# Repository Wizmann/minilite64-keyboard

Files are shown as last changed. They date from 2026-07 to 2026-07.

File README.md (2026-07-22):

# Minilite64 Keyboard

Minilite64 is a 64-key hot-swap keyboard built around a Waveshare
RP2040-Zero.  Its main PCB uses two copper layers; the Vial firmware exposes
four dynamic keymap layers.  The main keyboard PCB and controller carrier are
connected by a 21 mm-wide, 100 mm-long, 20-position 1.0 mm Type-A FFC.  The
design has no per-key lighting.

Assembly is main-board first and controller last.  Lock the main FFC end before
fastening the main PCB, connect the carrier/cover outside the case, then guide
the smooth rear service loop home and install the carrier-cover screws.

## Release contents

- `hardware/keyboard/Minilite64.kicad_pcb` — routed GH60-size main PCB
- `hardware/controller/RP2040_Zero_Carrier.kicad_pcb` — routed 40 x 36 mm carrier
- `hardware/mechanical/Minilite64_plate_fixed.dxf` — corrected plate for PC/FR4 ordering
- `hardware/mechanical/*.stl` and `*.step` — full-size and A1 standing mechanical parts
- `manufacturing/*_gerber.zip` — order-ready PCB packages
- `firmware/vial-qmk/keyboards/minilite64` — Vial-QMK keyboard source
- `firmware/releases/Minilite64_vial.uf2` — locally verified RP2040 firmware
- `docs/DESIGN_AND_REUSE_GUIDE.md` — design history, assembly notes, checks, and reusable lessons

Both PCBs currently report zero DRC violations and zero unconnected items.
The mechanical review reports zero intersections for the checked component,
mounting, controller, stabilizer, cover, and cable envelopes.
The main PCB front silkscreen also carries the complete corrected plate DXF at
1:1 scale for visual Gerber and bare-board inspection.

The checked-in UF2 was built with `arm-none-eabi-gcc 13.2.1`; its SHA-256 is
recorded in `firmware/releases/SHA256SUMS.txt`.

The current mechanical package is **prototype-only** until a real 100 mm FFC
has been installed and repeatedly serviced in a printed case.  Automated solid
checks cannot prove that a flexible cable will settle into the modeled scroll.

## Important fabrication note

Use `hardware/mechanical/Minilite64_plate_fixed.dxf`, not the original
`plate.dxf`.  The original drawing contains an obsolete screw relief merged
into the bottom-row Menu switch opening.  The fixed file removes that conflict
and adds two balanced bottom-row supports, for five round mounts plus two side
mounting slots in total.

See the [design and reuse guide](docs/DESIGN_AND_REUSE_GUIDE.md) before ordering
or assembling the first prototype.

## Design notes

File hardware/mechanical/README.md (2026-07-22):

# Mechanical File Manifest

Files with the same base name describe the same geometry in different formats:

- `.FCStd` — editable FreeCAD document.
- `.step` — neutral CAD exchange file for inspection, modification, or machining.
- `.stl` — triangulated mesh for slicers and 3D printing.

## Assembly review

- `Minilite64_assembly_review.FCStd`
- `Minilite64_assembly_review.step`
- `Minilite64_assembly_review.stl`

Combined case, cover, main PCB, plate, carrier, component keep-outs,
stabilizers, and spacers.  Use it to inspect placement and interference.  It is
not a single printable part.

## Case

- `Minilite64_case_full.*` — one-piece case in assembled orientation.  It uses
  a 307 x 106.5 mm Linhai/Case.step-inspired GH60-style plan, R5 plan corners,
  a 5 degree wedge, a 20.0 mm spacebar side, and a 29.318 mm number-row side.
  The tapered wall,
  R2 hand-contact rim, C1.2 lower edge break, and internal ribs follow the
  supplied references.  There is no controller tongue or rear projection.
- `Minilite64_case_A1_standing.*` — the same one-piece case rotated onto its
  front wall and 45 degrees across the bed.  Its stored bounds are about
  236.3 x 236.3 x 106.3 mm, so it fits the Bambu A1 with room for an
  approximately 8 mm brim.  Use this file for the preferred one-piece print.

The RP2040 carrier, service cover, USB-C tunnel, and rear-wall FFC service-loop
pocket are custom internal features.  They do not change the selected
rectangular outside envelope.

The PCB/plate stack and its seven mounting axes follow the 5 degree typing
plane; the carrier remains horizontal at the bottom for service access.

The 100 mm FFC is a service tether.  Connect and fasten the main PCB first,
connect the carrier/cover outside the case, then guide the smooth scroll into
its rounded rear pocket and install the cover screws.  The controller can be
removed later without disturbing the main PCB.

`Minilite64_assembly_review.*` also contains a named 65 mm controller service
pose with tangent cable exits.  The modeled service path is 94.762 mm long,
keeps 5.238 mm slack, reaches R3.6 at the fixed rear hairpin, and keeps the
cubic drop above R4.82.  The 81.625 mm straight-line value is only a theoretical
upper bound.  Use an FFC flexible body no thicker than 0.20 mm; the reinforced
ends may be 0.30 mm.

This package is prototype-only until a real cable has been fitted.  A solid
model cannot prove that the flexible strip will settle into the ideal scroll
instead of buckling during cover insertion.

The bottom has four circular pockets for nominal Ø10 x 1.5-2.0 mm adhesive
silicone feet.  Each pocket has an Ø11.2 mm body, 0.65 mm depth, and an Ø12 mm
tapered opening.  The extra diameter tolerates placement error; the shallow
lead-in avoids a sharp unsupported lip when the case is printed standing.

## Controller service part

- `Minilite64_service_cover.*` — removable bottom cover carrying the 40 x
  36 mm RP2040-Zero carrier.  It includes four carrier posts, cover screw
  holes, and a closed outside surface.  Remove the cover if physical
  BOOT/RESET recovery is ever required.

## Plate

- `Minilite64_plate_fixed.dxf` — corrected 1.5 mm plate drawing for PC/FR4
  fabrication.  This is the DXF to send to the plate vendor.
- `Minilite64_plate_print_fixed.*` — one-piece, 1.5 mm printable plate for a
  large printer.  It is primarily a fit-check model.
- `Minilite64_plate_A1_fitcheck.stl` — one A1-ready STL containing two flat
  printable halves.  The loose stepped joint avoids complete switch openings,
  uses a 0.4 mm total seam gap, and relies on switches and PCB screws for final
  alignment.  No glue is required for fit checking.
- `Minilite64_plate_spacer_print_7x.*` — 5 mm plate-to-PCB spacer; print seven
  copies, one at each retained mounting location.

The original root-level `plate.dxf` is preserved for provenance.  Do not send
it to manufacturing: it contains an obsolete screw relief merged into the
bottom-row Menu switch opening.  The files in this directory remove that
collision and add two symmetric bottom-row supports.  The finished plate has
five round mounts and two side mounting slots.

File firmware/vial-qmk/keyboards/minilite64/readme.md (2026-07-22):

# Minilite64 Vial firmware

Copy this directory to `vial-qmk/keyboards/minilite64`, then build with:

```sh
make minilite64:vial
```

Hold the top-left key while plugging in for Bootmagic reset. The default Fn1
layer also places `QK_BOOT` on the top-left key. Normal Vial remapping never
requires the physical BOOT/RESET buttons.

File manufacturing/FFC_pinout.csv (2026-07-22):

Main J1 pin | Carrier J1 pin | Net | RP2040-Zero pad
1 | 1 | COL0 | GP13
2 | 2 | COL1 | GP12
3 | 3 | COL2 | GP11
4 | 4 | COL3 | GP10
5 | 5 | COL4 | GP9
6 | 6 | COL5 | GP8
7 | 7 | COL6 | GP7
8 | 8 | COL7 | GP6
9 | 9 | COL8 | GP5
10 | 10 | COL9 | GP4
11 | 11 | COL10 | GP3
12 | 12 | COL11 | GP2
13 | 13 | COL12 | GP1
14 | 14 | COL13 | GP0
15 | 15 | ROW0 | GP29
16 | 16 | ROW1 | GP28
17 | 17 | ROW2 | GP27
18 | 18 | ROW3 | GP26
19 | 19 | ROW4 | GP15
20 | 20 | GND | GND

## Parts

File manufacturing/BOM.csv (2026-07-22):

Reference(s) | Qty | Value | Package | Assembly | Notes
SW1-SW64 | 64 | Kailh MX hot-swap socket CPG151101S11 | Kailh hotswap SMD | Hand solder | Socket on PCB bottom
D1-D64 | 64 | 1N4148W | SOD-123 | Hand solder | Large hand-solder pads; cathode stripe to ROW
J1 (main), J1 (carrier) | 2 | 20P 1.0mm bottom-contact flip-lock FFC/FPC connector | 20P 1.0mm SMT | Hand solder | Generic or equivalent; verify same footprint
FFC1 | 1 | 20P 1.0mm Type-A FFC, 100mm x 21mm | Same-side contacts | Purchased cable | No axial twist; flexible body <=0.20mm; prototype-fit the smooth service scroll
U1 | 1 | Waveshare RP2040-Zero 23.5x18mm USB-C | Castellated module | Hand solder | Mount component-side up; USB toward rear
H1-H5 main | 5 | M2 screw + 3.2x3mm heat-set insert | Mechanical | Assembly | Three original mounts plus two balanced bottom-row supports
S1-S2 main sides | 2 | M2 screw + 3.2x3mm heat-set insert | Mechanical | Assembly | Left/right DXF edge slots; screw heads retain PCB and plate
H1-H4 carrier | 4 | M2 screw + heat-set insert | Mechanical | Assembly | Four-corner mounting

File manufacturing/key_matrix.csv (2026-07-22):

Reference | Label | Matrix row | Matrix column | X mm | Y mm | Width U
SW1 | ~/` | 0 | 0 | 9.525 | 9.525 | 1.0
SW2 | !/1 | 0 | 1 | 28.575 | 9.525 | 1.0
SW3 | @/2 | 0 | 2 | 47.625 | 9.525 | 1.0
SW4 | #/3 | 0 | 3 | 66.675 | 9.525 | 1.0
SW5 | $/4 | 0 | 4 | 85.725 | 9.525 | 1.0
SW6 | %/5 | 0 | 5 | 104.775 | 9.525 | 1.0
SW7 | ^/6 | 0 | 6 | 123.825 | 9.525 | 1.0
SW8 | &/7 | 0 | 7 | 142.875 | 9.525 | 1.0
SW9 | */8 | 0 | 8 | 161.925 | 9.525 | 1.0
SW10 | (/9 | 0 | 9 | 180.975 | 9.525 | 1.0
SW11 | )/0 | 0 | 10 | 200.025 | 9.525 | 1.0
SW12 | _/- | 0 | 11 | 219.075 | 9.525 | 1.0
SW13 | +/= | 0 | 12 | 238.125 | 9.525 | 1.0
SW14 | Backspace | 0 | 13 | 266.700 | 9.525 | 2.0
SW15 | Tab | 1 | 0 | 14.288 | 28.575 | 1.5
SW16 | Q | 1 | 1 | 38.100 | 28.575 | 1.0
SW17 | W | 1 | 2 | 57.150 | 28.575 | 1.0
SW18 | E | 1 | 3 | 76.200 | 28.575 | 1.0
SW19 | R | 1 | 4 | 95.250 | 28.575 | 1.0
SW20 | T | 1 | 5 | 114.300 | 28.575 | 1.0
SW21 | Y | 1 | 6 | 133.350 | 28.575 | 1.0
SW22 | U | 1 | 7 | 152.400 | 28.575 | 1.0
SW23 | I | 1 | 8 | 171.450 | 28.575 | 1.0
SW24 | O | 1 | 9 | 190.500 | 28.575 | 1.0
SW25 | P | 1 | 10 | 209.550 | 28.575 | 1.0
SW26 | {/[ | 1 | 11 | 228.600 | 28.575 | 1.0
SW27 | }/] | 1 | 12 | 247.650 | 28.575 | 1.0
SW28 | |/\ | 1 | 13 | 271.463 | 28.575 | 1.5
SW29 | Caps Lock | 2 | 0 | 16.669 | 47.625 | 1.75
SW30 | A | 2 | 1 | 42.863 | 47.625 | 1.0
SW31 | S | 2 | 2 | 61.913 | 47.625 | 1.0
SW32 | D | 2 | 3 | 80.963 | 47.625 | 1.0
SW33 | F | 2 | 4 | 100.013 | 47.625 | 1.0
SW34 | G | 2 | 5 | 119.062 | 47.625 | 1.0
SW35 | H | 2 | 6 | 138.113 | 47.625 | 1.0
SW36 | J | 2 | 7 | 157.162 | 47.625 | 1.0
SW37 | K | 2 | 8 | 176.213 | 47.625 | 1.0
SW38 | L | 2 | 9 | 195.263 | 47.625 | 1.0
SW39 | :/; | 2 | 10 | 214.312 | 47.625 | 1.0
SW40 | "/' | 2 | 11 | 233.363 | 47.625 | 1.0
SW41 | Enter | 2 | 12 | 264.319 | 47.625 | 2.25
SW42 | Shift | 3 | 0 | 21.431 | 66.675 | 2.25
SW43 | Z | 3 | 1 | 52.388 | 66.675 | 1.0
SW44 | X | 3 | 2 | 71.438 | 66.675 | 1.0
SW45 | C | 3 | 3 | 90.487 | 66.675 | 1.0
SW46 | V | 3 | 4 | 109.538 | 66.675 | 1.0
SW47 | B | 3 | 5 | 128.588 | 66.675 | 1.0
SW48 | N | 3 | 6 | 147.638 | 66.675 | 1.0
SW49 | M | 3 | 7 | 166.688 | 66.675 | 1.0
SW50 | </, | 3 | 8 | 185.738 | 66.675 | 1.0
SW51 | >/. | 3 | 9 | 204.787 | 66.675 | 1.0
SW52 | ?// | 3 | 10 | 223.838 | 66.675 | 1.0
SW53 | Shift | 3 | 11 | 259.556 | 66.675 | 2.75
SW54 | Ctrl | 4 | 0 | 11.906 | 85.725 | 1.25
SW55 | Win | 4 | 1 | 35.719 | 85.725 | 1.25
SW56 | Alt | 4 | 2 | 59.531 | 85.725 | 1.25
SW57 | Fn1 | 4 | 3 | 83.344 | 85.725 | 1.25
SW58 |  | 4 | 4 | 121.444 | 85.725 | 2.75
SW59 | Fn2 | 4 | 5 | 159.544 | 85.725 | 1.25
SW60 | Menu | 4 | 6 | 183.356 | 85.725 | 1.25
SW61 | Fn3 | 4 | 7 | 204.787 | 85.725 | 1.0
SW62 | Alt | 4 | 8 | 226.219 | 85.725 | 1.25
SW63 | Win | 4 | 9 | 250.031 | 85.725 | 1.25
SW64 | Ctrl | 4 | 10 | 273.844 | 85.725 | 1.25

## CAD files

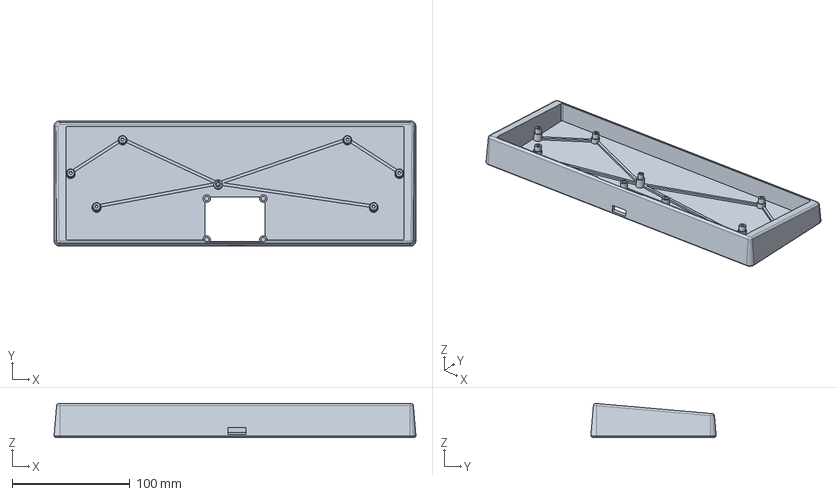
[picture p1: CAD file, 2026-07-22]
hardware/mechanical/Minilite64_case_full.step
306.8 x 106.3 x 28.9 mm

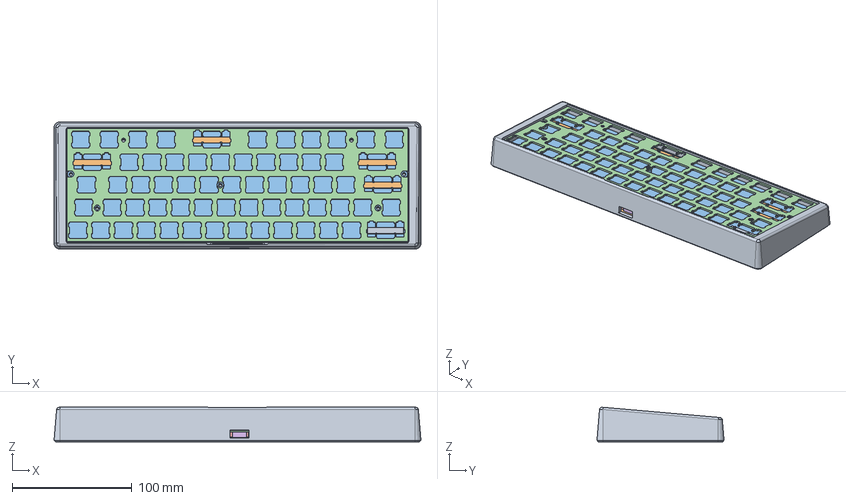
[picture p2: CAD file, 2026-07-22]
hardware/mechanical/Minilite64_assembly_review.step
306.8 x 106.3 x 28.9 mm

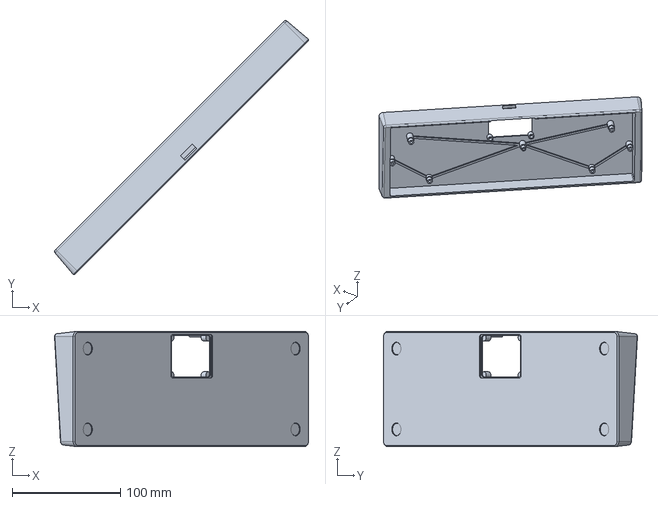
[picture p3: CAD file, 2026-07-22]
hardware/mechanical/Minilite64_case_A1_standing.step
234.2 x 234.2 x 106.3 mm

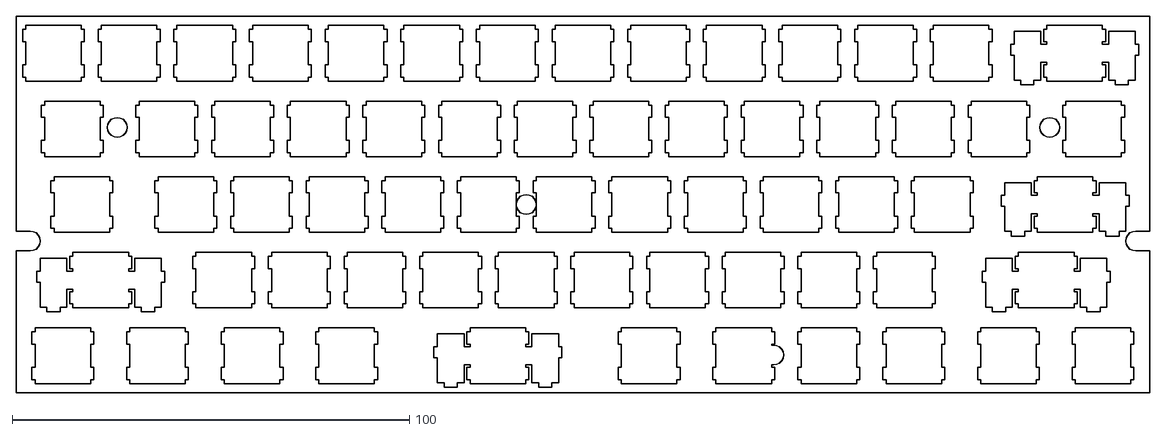
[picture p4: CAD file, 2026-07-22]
plate.dxf
285.4 x 94.9

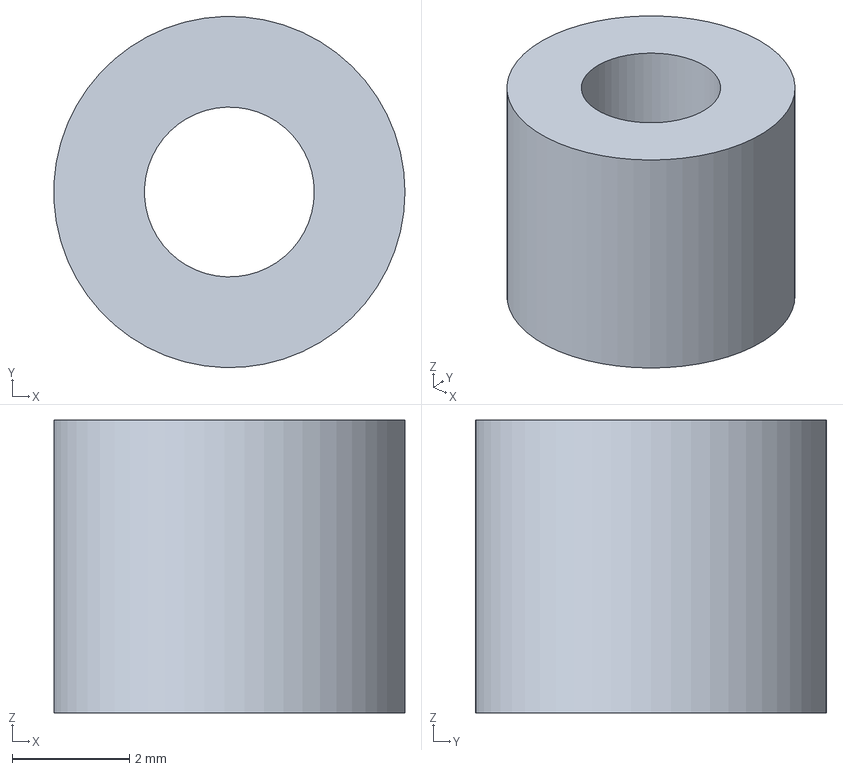
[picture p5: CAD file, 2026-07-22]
hardware/mechanical/Minilite64_plate_spacer_print_7x.step
6.00 x 6.00 x 5.00 mm

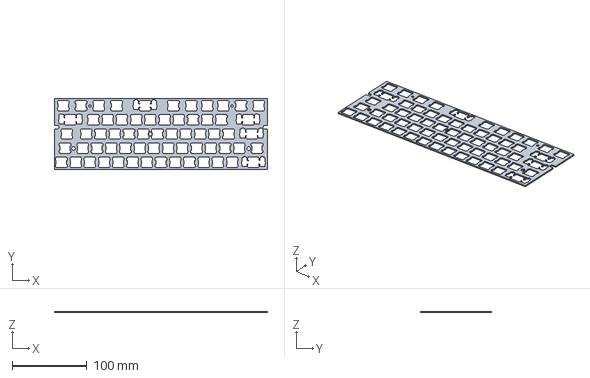
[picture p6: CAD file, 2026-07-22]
hardware/mechanical/Minilite64_plate_print_fixed.step
285.4 x 94.9 x 1.50 mm

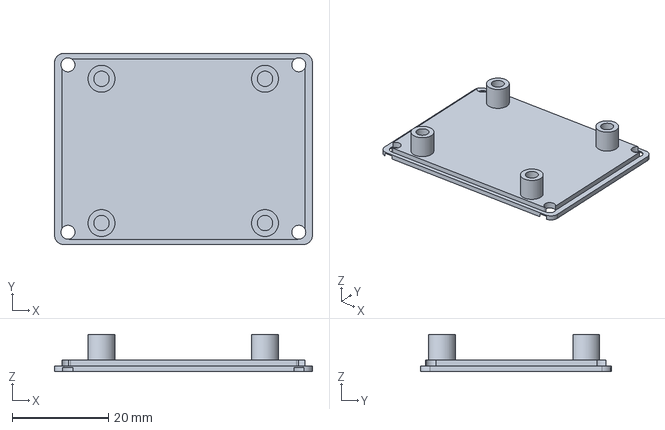
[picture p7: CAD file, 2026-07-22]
hardware/mechanical/Minilite64_service_cover.step
53.7 x 39.8 x 7.70 mm

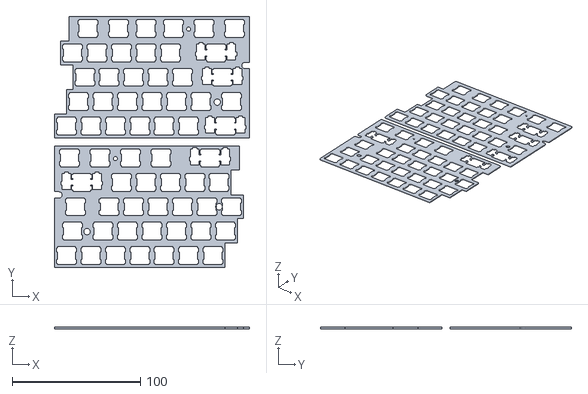
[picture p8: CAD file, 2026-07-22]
hardware/mechanical/Minilite64_plate_A1_fitcheck.stl
152.0 x 195.9 x 1.50

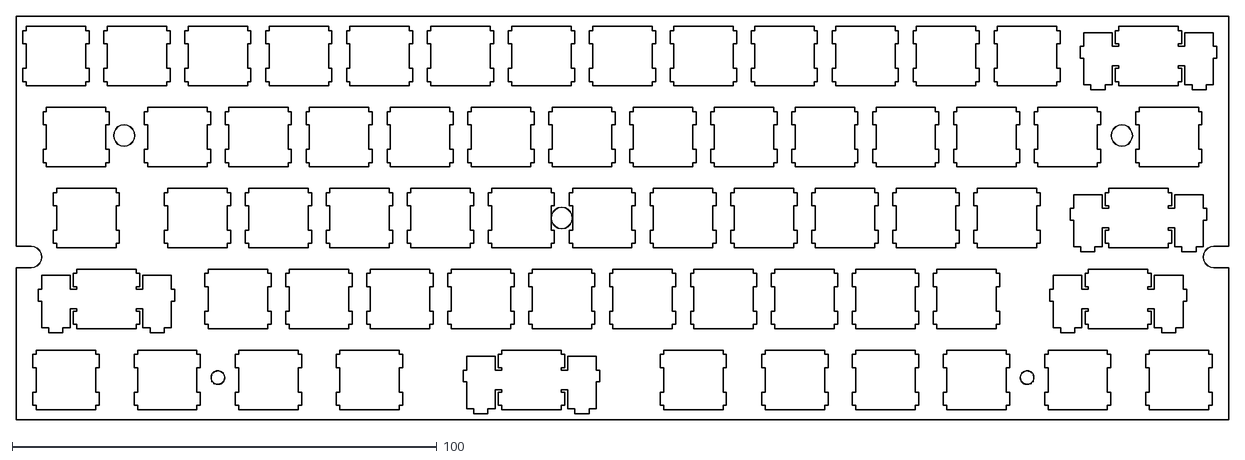
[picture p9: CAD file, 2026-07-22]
hardware/mechanical/Minilite64_plate_fixed.dxf
285.4 x 94.9

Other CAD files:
hardware/mechanical/Minilite64_plate_spacer_print_5x.step
hardware/mechanical/Minilite64_assembly_review.FCStd
hardware/mechanical/Minilite64_assembly_review.stl
hardware/mechanical/Minilite64_case_A1_standing.FCStd
hardware/mechanical/Minilite64_case_A1_standing.stl
hardware/mechanical/Minilite64_case_full.FCStd
hardware/mechanical/Minilite64_case_full.stl
hardware/mechanical/Minilite64_plate_print_fixed.FCStd
hardware/mechanical/Minilite64_plate_print_fixed.stl
hardware/mechanical/Minilite64_plate_spacer_print_7x.FCStd
hardware/mechanical/Minilite64_plate_spacer_print_7x.stl
hardware/mechanical/Minilite64_service_cover.FCStd
hardware/mechanical/Minilite64_service_cover.stl

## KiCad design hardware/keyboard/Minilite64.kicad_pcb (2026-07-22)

Board: 2 copper layers, 134 parts (1 on the bottom side), 83 nets.

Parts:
D1, D2, D3, D4, D5, D6, D7, D8, D9, D10, D11, D12, D13, D14: 1N4148W SOD-123; SOD-123_HandSolder_Horizontal
D15, D16, D17, D18, D19, D20, D21, D22, D23, D24, D25, D26, D27, D28, D29, D30, D31, D32, D33, D34, D35, D36, D37, D38, D39, D40, D41, D42, D43, D44, D45, D46, D47, D48, D49, D50, D51, D52, D53, D54, D55, D56, D57, D58, D59, D60, D61, D62, D63, D64: 1N4148W SOD-123; SOD-123_HandSolder
H1, H2, H3: M2 clearance; MountingHole_2.7mm
H4, H5: M2 clearance; MountingHole_2.4mm
J1: 20P 1.0mm FFC ZIF bottom-contact; FFC_20P_1.0mm_BottomContact_Back
SW1: Kailh MX hotswap / ~ / `; Kailh_MX_Hotswap
SW2: Kailh MX hotswap / ! / 1; Kailh_MX_Hotswap
SW3: Kailh MX hotswap / @ / 2; Kailh_MX_Hotswap
SW4: Kailh MX hotswap / # / 3; Kailh_MX_Hotswap
SW5: Kailh MX hotswap / $ / 4; Kailh_MX_Hotswap
SW6: Kailh MX hotswap / % / 5; Kailh_MX_Hotswap
SW7: Kailh MX hotswap / ^ / 6; Kailh_MX_Hotswap
SW8: Kailh MX hotswap / & / 7; Kailh_MX_Hotswap
SW9: Kailh MX hotswap / * / 8; Kailh_MX_Hotswap
SW10: Kailh MX hotswap / ( / 9; Kailh_MX_Hotswap
SW11: Kailh MX hotswap / ) / 0; Kailh_MX_Hotswap
SW12: Kailh MX hotswap / _ / -; Kailh_MX_Hotswap
SW13: Kailh MX hotswap / + / =; Kailh_MX_Hotswap
SW14: Kailh MX hotswap / Backspace; Kailh_MX_Hotswap
SW15: Kailh MX hotswap / Tab; Kailh_MX_Hotswap
SW16: Kailh MX hotswap / Q; Kailh_MX_Hotswap
SW17: Kailh MX hotswap / W; Kailh_MX_Hotswap
SW18: Kailh MX hotswap / E; Kailh_MX_Hotswap
SW19: Kailh MX hotswap / R; Kailh_MX_Hotswap
SW20: Kailh MX hotswap / T; Kailh_MX_Hotswap
SW21: Kailh MX hotswap / Y; Kailh_MX_Hotswap
SW22: Kailh MX hotswap / U; Kailh_MX_Hotswap
SW23: Kailh MX hotswap / I; Kailh_MX_Hotswap
SW24: Kailh MX hotswap / O; Kailh_MX_Hotswap
SW25: Kailh MX hotswap / P; Kailh_MX_Hotswap
SW26: Kailh MX hotswap / { / [; Kailh_MX_Hotswap
SW27: Kailh MX hotswap / } / ]; Kailh_MX_Hotswap
SW28: Kailh MX hotswap / | / \; Kailh_MX_Hotswap
SW29: Kailh MX hotswap / Caps Lock; Kailh_MX_Hotswap
SW30: Kailh MX hotswap / A; Kailh_MX_Hotswap
SW31: Kailh MX hotswap / S; Kailh_MX_Hotswap
SW32: Kailh MX hotswap / D; Kailh_MX_Hotswap
SW33: Kailh MX hotswap / F; Kailh_MX_Hotswap
SW34: Kailh MX hotswap / G; Kailh_MX_Hotswap
SW35: Kailh MX hotswap / H; Kailh_MX_Hotswap
SW36: Kailh MX hotswap / J; Kailh_MX_Hotswap
SW37: Kailh MX hotswap / K; Kailh_MX_Hotswap
SW38: Kailh MX hotswap / L; Kailh_MX_Hotswap
SW39: Kailh MX hotswap / : / ;; Kailh_MX_Hotswap
SW40: Kailh MX hotswap / " / '; Kailh_MX_Hotswap
SW41: Kailh MX hotswap / Enter; Kailh_MX_Hotswap
SW42, SW53: Kailh MX hotswap / Shift; Kailh_MX_Hotswap
SW43: Kailh MX hotswap / Z; Kailh_MX_Hotswap
SW44: Kailh MX hotswap / X; Kailh_MX_Hotswap
SW45: Kailh MX hotswap / C; Kailh_MX_Hotswap
SW46: Kailh MX hotswap / V; Kailh_MX_Hotswap
SW47: Kailh MX hotswap / B; Kailh_MX_Hotswap
SW48: Kailh MX hotswap / N; Kailh_MX_Hotswap
SW49: Kailh MX hotswap / M; Kailh_MX_Hotswap
SW50: Kailh MX hotswap / < / ,; Kailh_MX_Hotswap
SW51: Kailh MX hotswap / > / .; Kailh_MX_Hotswap
SW52: Kailh MX hotswap / ? / /; Kailh_MX_Hotswap
SW54, SW64: Kailh MX hotswap / Ctrl; Kailh_MX_Hotswap
SW55, SW63: Kailh MX hotswap / Win; Kailh_MX_Hotswap
SW56, SW62: Kailh MX hotswap / Alt; Kailh_MX_Hotswap
SW57: Kailh MX hotswap / Fn1; Kailh_MX_Hotswap
SW58: Kailh MX hotswap /; Kailh_MX_Hotswap
SW59: Kailh MX hotswap / Fn2; Kailh_MX_Hotswap
SW60: Kailh MX hotswap / Menu; Kailh_MX_Hotswap
SW61: Kailh MX hotswap / Fn3; Kailh_MX_Hotswap

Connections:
COL0: J1.1, SW1.1, SW15.1, SW29.1, SW42.1, SW54.1
COL1: J1.2, SW2.1, SW16.1, SW30.1, SW43.1, SW55.1
COL2: J1.3, SW3.1, SW17.1, SW31.1, SW44.1, SW56.1
COL3: J1.4, SW4.1, SW18.1, SW32.1, SW45.1, SW57.1
COL4: J1.5, SW5.1, SW19.1, SW33.1, SW46.1, SW58.1
COL5: J1.6, SW6.1, SW20.1, SW34.1, SW47.1, SW59.1
COL6: J1.7, SW7.1, SW21.1, SW35.1, SW48.1, SW60.1
COL7: J1.8, SW8.1, SW22.1, SW36.1, SW49.1, SW61.1
COL8: J1.9, SW9.1, SW23.1, SW37.1, SW50.1, SW62.1
COL9: J1.10, SW10.1, SW24.1, SW38.1, SW51.1, SW63.1
COL10: J1.11, SW11.1, SW25.1, SW39.1, SW52.1, SW64.1
COL11: J1.12, SW12.1, SW26.1, SW40.1, SW53.1
COL12: J1.13, SW13.1, SW27.1, SW41.1
COL13: J1.14, SW14.1, SW28.1
KEY1_D: D1.1, SW1.2
KEY2_D: D2.1, SW2.2
KEY3_D: D3.1, SW3.2
KEY4_D: D4.1, SW4.2
KEY5_D: D5.1, SW5.2
KEY6_D: D6.1, SW6.2
KEY7_D: D7.1, SW7.2
KEY8_D: D8.1, SW8.2
KEY9_D: D9.1, SW9.2
KEY10_D: D10.1, SW10.2
KEY11_D: D11.1, SW11.2
KEY12_D: D12.1, SW12.2
KEY13_D: D13.1, SW13.2
KEY14_D: D14.1, SW14.2
KEY15_D: D15.1, SW15.2
KEY16_D: D16.1, SW16.2
KEY17_D: D17.1, SW17.2
KEY18_D: D18.1, SW18.2
KEY19_D: D19.1, SW19.2
KEY20_D: D20.1, SW20.2
KEY21_D: D21.1, SW21.2
KEY22_D: D22.1, SW22.2
KEY23_D: D23.1, SW23.2
KEY24_D: D24.1, SW24.2
KEY25_D: D25.1, SW25.2
KEY26_D: D26.1, SW26.2
KEY27_D: D27.1, SW27.2
KEY28_D: D28.1, SW28.2
KEY29_D: D29.1, SW29.2
KEY30_D: D30.1, SW30.2
KEY31_D: D31.1, SW31.2
KEY32_D: D32.1, SW32.2
KEY33_D: D33.1, SW33.2
KEY34_D: D34.1, SW34.2
KEY35_D: D35.1, SW35.2
KEY36_D: D36.1, SW36.2
KEY37_D: D37.1, SW37.2
KEY38_D: D38.1, SW38.2
KEY39_D: D39.1, SW39.2
KEY40_D: D40.1, SW40.2
KEY41_D: D41.1, SW41.2
KEY42_D: D42.1, SW42.2
KEY43_D: D43.1, SW43.2
KEY44_D: D44.1, SW44.2
KEY45_D: D45.1, SW45.2
KEY46_D: D46.1, SW46.2
KEY47_D: D47.1, SW47.2
KEY48_D: D48.1, SW48.2
KEY49_D: D49.1, SW49.2
KEY50_D: D50.1, SW50.2
KEY51_D: D51.1, SW51.2
KEY52_D: D52.1, SW52.2
KEY53_D: D53.1, SW53.2
KEY54_D: D54.1, SW54.2
KEY55_D: D55.1, SW55.2
KEY56_D: D56.1, SW56.2
KEY57_D: D57.1, SW57.2
KEY58_D: D58.1, SW58.2
KEY59_D: D59.1, SW59.2
KEY60_D: D60.1, SW60.2
KEY61_D: D61.1, SW61.2
KEY62_D: D62.1, SW62.2
KEY63_D: D63.1, SW63.2
KEY64_D: D64.1, SW64.2
ROW0: D1.2, D2.2, D3.2, D4.2, D5.2, D6.2, D7.2, D8.2, D9.2, D10.2, D11.2, D12.2, D13.2, D14.2, J1.15
ROW1: D15.2, D16.2, D17.2, D18.2, D19.2, D20.2, D21.2, D22.2, D23.2, D24.2, D25.2, D26.2, D27.2, D28.2, J1.16
ROW2: D29.2, D30.2, D31.2, D32.2, D33.2, D34.2, D35.2, D36.2, D37.2, D38.2, D39.2, D40.2, D41.2, J1.17
ROW3: D42.2, D43.2, D44.2, D45.2, D46.2, D47.2, D48.2, D49.2, D50.2, D51.2, D52.2, D53.2, J1.18
ROW4: D54.2, D55.2, D56.2, D57.2, D58.2, D59.2, D60.2, D61.2, D62.2, D63.2, D64.2, J1.19

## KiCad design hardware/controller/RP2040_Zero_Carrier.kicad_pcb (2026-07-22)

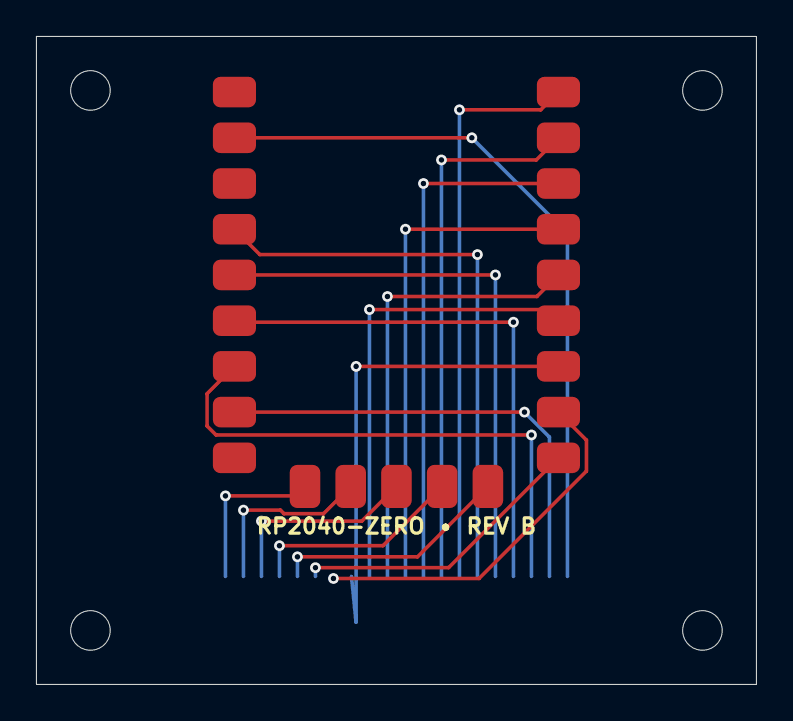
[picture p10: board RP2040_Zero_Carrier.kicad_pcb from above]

Board: 2 copper layers, 40.0 x 36.0 mm, 6 parts (1 on the bottom side), 20 nets.

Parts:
H1, H2, H3, H4: M2.5 clearance; MountingHole_2.2mm
J1: 20P 1.0mm FFC ZIF bottom-contact; FFC_20P_1.0mm_BottomContact_Back
U1: Waveshare RP2040-Zero; Waveshare_RP2040_Zero_Castellated

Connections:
COL0: J1.1, U1.GP13
COL1: J1.2, U1.GP12
COL2: J1.3, U1.GP11
COL3: J1.4, U1.GP10
COL4: J1.5, U1.GP9
COL5: J1.6, U1.GP8
COL6: J1.7, U1.GP7
COL7: J1.8, U1.GP6
COL8: J1.9, U1.GP5
COL9: J1.10, U1.GP4
COL10: J1.11, U1.GP3
COL11: J1.12, U1.GP2
COL12: J1.13, U1.GP1
COL13: J1.14, U1.GP0
GND: J1.20, U1.GND
ROW0: J1.15, U1.GP29
ROW1: J1.16, U1.GP28
ROW2: J1.17, U1.GP27
ROW3: J1.18, U1.GP26
ROW4: J1.19, U1.GP15

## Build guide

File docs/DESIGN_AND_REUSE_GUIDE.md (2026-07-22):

# Minilite64 Design, Assembly, and Reuse Guide

This document records how Minilite64 was designed, what was verified, what
failed during the process, and which practices should be reused on the next
keyboard project.  It is intentionally more explicit than a normal build
guide because the difficult parts were mechanical coordination and source-of-
truth management rather than the keyboard matrix itself.

## 1. Product definition

Minilite64 is based on the supplied 64-key KLE and plate DXF.  The confirmed
requirements are:

- 64 MX-compatible switches in a 5 x 14 sparse matrix.
- Kailh CPG151101S11-style hot-swap sockets on the PCB bottom.
- One hand-solderable SOD-123 1N4148W diode per key.
- No keyboard lighting.  The RP2040-Zero's onboard indicators are unaffected.
- A two-copper-layer main PCB with a rectangular GH60-style envelope and no PCB tongue.
- A separate Waveshare RP2040-Zero carrier.
- A 21 mm-wide, 100 mm-long, 20-position 1.0 mm Type-A/same-side FFC.
- Vial/VIA remapping, four dynamic layers, Bootmagic, and a firmware boot key.
- A PC or FR4 plate, 1.5 mm thick, plus printable verification plates.
- A Case.step-inspired wedge case, a bottom service cover, and a one-piece
  Bambu A1 standing print.

## 2. Electrical architecture

### Main PCB

The main PCB is 285.45 x 94.95 mm in its final edge-cut bounding box.  It uses
two copper layers, 0.20 mm minimum routed track width, 0.20 mm minimum routed
clearance, 0.30 mm vias, and a nominal 1.60 mm board thickness.

The switch matrix has five rows and fourteen columns.  Diode direction is
`COL2ROW`.  Both bottom-contact ZIF mouths face the number-row/rear side.  The
specified Type-A cable forms a smooth service scroll in the internal rear-wall pocket, so
the conductors stay flat without axial twist.  Pin numbers connect straight
through:

| Main J1 | Carrier J1 | Net | RP2040-Zero pad |
|---:|---:|---|---|
| 1 | 1 | COL0 | GP13 |
| 2-14 | 2-14 | COL1-COL13 | GP12 through GP0 |
| 15-19 | 15-19 | ROW0-ROW4 | GP29, GP28, GP27, GP26, GP15 |
| 20 | 20 | GND | GND |

The final main board includes seven usable mounting locations:

- Original round mounts: `(25.57496, 28.22478)`, `(128.57596, 47.62558)`, and
  `(260.42446, 28.22478)` mm.
- Balanced bottom-row M2 mounts: `(47.625, 85.20)` and `(238.125, 85.20)` mm.
- Side-slot screw axes: `(3.65, 56.824)` and `(282.10, 56.824)` mm.

The bottom-row screw relief near the Menu key is deliberately absent.  It
overlapped the switch opening and would have collided with the switch/hot-swap
assembly.  The two replacement mounts are symmetric about the keyboard center,
sit in full material between adjacent 1.25U switches, and avoid the spacebar
stabilizer.  The PCB uses 2.4 mm NPTH holes at these new locations; the plate
uses 3.2 mm clearance holes.

### RP2040-Zero carrier

The carrier is 40 x 36 mm with four 2.2 mm holes at `(3,3)`, `(37,3)`,
`(3,33)`, and `(37,33)` mm.  The RP2040-Zero is mounted on F.Cu and the FFC
connector is on B.Cu.  In the case, the module side faces the bottom service
cover.  The cover intentionally has no external BOOT/RESET opening.  Normal
remapping uses Vial and the keymap provides `QK_BOOT`; if damaged firmware
cannot enter its bootloader, remove the service cover to press the physical
buttons.  Removing the cover also brings the carrier out far enough to reach
the FFC latch without sharply folding the cable.

Do not regenerate the routed carrier from the old seed.  The generator now
writes an optional unrouted carrier seed only to `build/` when invoked with
`--write-carrier-seed`; it never overwrites the routed board in `hardware/`.

## 3. Coordinate systems and the plate correction

The most important geometry lesson was that the DXF Y axis and the KLE/KiCad Y
axis point in opposite directions.  Treating them as identical incorrectly
made a valid mounting hole appear to collide with Shift.

The conversion used here mirrors the DXF about its own center and maps that
center to the PCB center:

```text
pcb_x = dxf_x + pcb_center_x - dxf_center_x
pcb_y = pcb_center_y - (dxf_y - dxf_center_y)
```

The original DXF contains 68 closed connected contours, but one switch contour
has 33 segments because an obsolete circular screw relief was merged into the
bottom-row Menu opening.  The corrected file replaces that merged contour with
a normal MX opening and adds the two bottom-row clearance holes.  The corrected
DXF has 70 closed contours and no 33-segment internal contour.

Always order the plate from:

`hardware/mechanical/Minilite64_plate_fixed.dxf`

The main PCB front silkscreen reproduces all 1,626 line segments from this
corrected DXF: outside edge, MX/stabilizer openings, and mounting holes.  This
is a visual verification layer, not a routing or fabrication boundary.  Check
it in the Gerber viewer before ordering and compare it directly on the first
bare PCB.

The outside verification line intentionally follows the 1:1 plate edge only
0.128 mm from the routed PCB edge after line width is included.  The keyboard
project therefore ignores only KiCad's silkscreen-to-board-edge warning; all
copper, hole, connectivity, and other silkscreen checks remain enabled.  The
branding is on B.Silkscreen so it does not merge with the verification lines.

Keep the original `plate.dxf` only as provenance.

## 4. Routing lessons

1. Reserve the FFC escape before routing the matrix.  A 20-pin connector at
   1.0 mm pitch is easy to place and surprisingly hard to escape after the
   row/column buses occupy both layers.
2. Rotating the top-row hot-swap sockets opened the shallow rear corridor used
   by the main FFC connector.
3. Move diodes when they block a route, but check the full physical envelope:
   socket body, stabilizer wire, screw head, case post, and soldering-iron
   access.
4. Do not extend row buses decoratively to the board edge.  The first revision
   left five harmless dangling ends.  Terminating each row bus on its first and
   last diode stub removed all five warnings and cleared the right mounting
   notch.
5. Right-angle traces are not an electrical concern for a keyboard matrix, but
   clean 45-degree routing remains useful because it is easier to inspect and
   leaves predictable mechanical corridors.
6. A rectangular PCB can still contain edge mounting notches.  "No tongue"
   should not be interpreted as "discard all edge mounting geometry."

## 5. Mechanical architecture

GH60 defines a PCB and mounting ecosystem, not one official case shell.  The
case exterior therefore combines the supplied references with the GH60 PCB
datum:

- The original [GH60 project](https://github.com/komar007/gh60) supplies the
  PCB and mounting datum.
- The supplied Linhai GH60 3MF supplies the 307 x 106.5 mm outside plan and its
  proven 45 degree standing-print strategy.
- The supplied `Case.step` measures approximately 303.64 x 115.22 x 33.47 mm.
  Its main profile is about 22.91 mm at the front and 32.06 mm at the rear,
  with a 5 degree typing plane, tapered walls, rounded hand-contact edges, and
  triangulated internal ribs.

The resulting Minilite64 case uses a nominal 307 x 106.5 mm GH60-style plan,
R5 plan corners, a 20.0 mm spacebar-side low edge, a 29.318 mm number-row-side
high edge, and a 5 degree wedge.  It
adds a 2.5 mm wall taper, an R2 upper edge, and a C1.2 lower edge break so the
printed shell does not leave a sharp hand-contact edge.  The previous flat tray
and its rear controller projection were removed.  The carrier was moved
forward so the service cover, USB-C tunnel, and FFC C-bend pocket all fit inside
the rectangular exterior.

Four recessed adhesive-foot locations support the case near its corners.
They target nominal Ø10 x 1.5-2.0 mm silicone pads.  The pocket body is Ø11.2
x 0.65 mm, providing 0.6 mm radial placement allowance, and the opening grows
to Ø12 mm through a shallow tapered lead-in.  At least 1.75 mm of the 2.4 mm
floor remains below each pocket.  Four feet are intentional: additional hard
support points make a slightly warped print more likely to rock.

The main PCB, plate, spacers, screw axes, and upper post sections share the
5 degree plane.  Approximate assembled heights are:

| Item | Number-row/high datum | Spacebar/low datum |
|---|---:|---:|
| Case floor | 0-2.4 mm | 0-2.4 mm |
| Carrier PCB | 7.7-9.3 mm | horizontal |
| Main PCB bottom | 19.1 mm | 10.81 mm |
| Plate bottom | 25.7 mm | 17.41 mm |
| Case rim | 29.318 mm exterior | 20.0 mm exterior |

The height values at the PCB edges differ slightly from the case exterior-edge
values because the PCB is inset from the front and rear walls.

The 100 mm Type-A FFC exits the main ZIF toward the rear wall, forms a loose
2.5-turn service scroll in the internal pocket, and then runs forward above
the carrier PCB.  The 22.5 mm-wide envelope gives the 21 mm cable 0.75 mm
clearance per side.  The modeled neutral-axis radius grows from R3.2 to R4.0;
there are no sharp accordion folds and no long-axis twist.  The pocket is
internal, so the GH60 exterior remains unchanged.

The 81.625 mm straight-line number in the generated review is only a theoretical
upper bound and is not used as the release gate.  A separate service pose keeps
the rear R3.6 hairpin inside the blind pocket, applies tangent exits at both
ZIFs, and holds the connected carrier/cover 65 mm below its installed position.
That constructed path is 94.762 mm long, retains 5.238 mm slack, has an overall
minimum radius of R3.6 at the fixed rear hairpin and R4.82 on the cubic drop,
and has zero modeled intersections.  This supports the
required main-first assembly: connect and fasten the main PCB, connect the
carrier outside the case, guide the scroll home, and install the cover screws.

Specify an FFC flexible-body thickness of 0.20 mm or less; 0.30 mm is acceptable
only at the reinforced contact ends.  The scroll radial pitch is 0.32 mm, which
leaves at least 0.12 mm between 0.20 mm flexible layers.  The USB tunnel was
lowered to leave a 1.25 mm printed web to the cable pocket, and rear-wall skin
is 2.075 mm.  These are modeled values, not a substitute for a physical fit.

The assembled-orientation case is 307 mm long, but the one-piece
`Minilite64_case_A1_standing.stl` is stored front-wall-down and rotated 45
degrees.  Its approximate slicer bounds are 236.3 x 236.3 x 106.3 mm, leaving
room for an approximately 8 mm brim on the Bambu A1.  Use the standing file as
the one-piece print.  The printable full plate is primarily a fit-check model;
order the final plate in 1.5 mm PC or FR4 from the corrected DXF.

For A1 fit checking, `Minilite64_plate_A1_fitcheck.stl` contains both plate
halves already laid flat on one bed.  Its stepped seam follows the material
webs between rows and columns, with 0.4 mm total clearance.  The joint is an
alignment feature rather than a structural connection: assemble it loosely,
insert the nearby switches into the PCB, then tighten the plate screws.  Glue
is unnecessary for dimensional verification.

For the standing case, keep the stored orientation, add an 8-10 mm brim, and
inspect the slicer's support preview around the horizontal insert bosses,
service opening, and internal ribs.  Do not scale the model to make it fit.
Print a small insert-pilot test coupon to tune screw clearances for the chosen
filament before committing to the full case.

## 6. Mechanical checks performed

`build/mechanical_review.json` is generated from actual FreeCAD solids plus
conservative component envelopes.  The following intersections must remain
zero:

- Main components versus main mounting bosses.
- Main components versus the controller assembly.
- Controller assembly versus the case.
- Service cover versus the case.
- Main PCB and plate versus case walls.
- Plate-mount stabilizer envelopes versus the seven plate spacers.
- FFC corridor versus the case and mounting bosses.

The hot-swap keep-outs initially collided with three full-diameter posts.  The
final main posts use a wide lower body below component height and normally a
6 mm upper boss.  The legacy center location retains a 4.8 mm neck because a
6 mm neck intersects its socket envelope.  Each main boss has a 2.8 mm pilot
for a short M2 heat-set insert with nominal 3.2 mm OD and 3 mm length.  Their
axes follow the 5 degree PCB normal.  The service-cover screw towers were also
moved outside the 40 mm carrier outline after the first solid-intersection pass
found an overlap.

These checks are envelope checks, not a substitute for a physical prototype.
Print the fit-check plate, install representative switches, sockets,
stabilizers, screws, and an actual FFC, then print the case.

The mechanical release remains **prototype-only** until a real 100 x 21 mm FFC
is shown to settle into the service pocket without creasing or springing into
the controller, and the controller-last operation is repeated several times.

## 7. Assembly order

1. Inspect both PCBs under magnification and check for solder bridges.
2. Solder the 64 diodes with the cathode stripe toward the row bus.
3. Solder the 64 Kailh hot-swap sockets on the main PCB bottom.
4. Solder both 20P ZIF connectors.  Confirm that both mouths face the rear and
   pin 1 is on the COL0 side before installing the FFC.
5. Solder the RP2040-Zero castellations to the carrier with USB-C toward the
   rear opening.
6. Heat-set the seven main M2 inserts with a temperature-controlled tip.  Keep
   each insert square to the tilted boss and stop flush; do not force it deeper
   than the 3 mm insert length.
7. Mount the carrier to the service cover, module side toward the closed cover
   surface; the modeled standoffs provide component clearance.
8. Install the seven 5 mm plate spacers and prepare the main PCB/plate stack.
   Use the two new symmetric bottom-row supports, not the deleted Menu-key
   screw location, but do not install the main PCB screws yet.
9. Insert and lock the Type-A FFC at main-board J1, guide the free end through
   the rear service-loop pocket, then lower and screw down the main PCB.
10. Hold the carrier/cover outside the bottom opening, insert and lock the free
    FFC end at carrier J1, and inspect the latch.  Guide the cable into the
    rounded service-scroll pocket without twisting it, seat the carrier cover,
    then install the cover screws.
11. Flash the UF2 and perform a full matrix test before fitting keycaps.

For normal remapping, use Vial.  The physical BOOT/RESET buttons should rarely
be needed after the first flash.  The default Fn1 layer provides `QK_BOOT` on
the top-left key, and Bootmagic is enabled.

## 8. Firmware build

The source lives at `firmware/vial-qmk/keyboards/minilite64`.  Copy that folder
into a Vial-QMK checkout and build:

```bash
make minilite64:vial
```

The confirmed toolchain is Vial-QMK plus `arm-none-eabi-gcc` 13.2.1.  On WSL,
build from the Linux filesystem rather than `/mnt/c` or `/mnt/e`; QMK scans
tens of thousands of small files and is dramatically slower on a mounted
Windows filesystem.

## 9. Reproducing generated artifacts

Main PCB and metadata, without touching the routed carrier:

```powershell
python tools/generate_hardware.py
```

Optional unrouted carrier seed:

```powershell
python tools/generate_hardware.py --write-carrier-seed
```

Mechanical outputs with FreeCAD:

```powershell
freecadcmd.exe -c "exec(compile(open(r'E:\Code\Minilite\tools\generate_mechanical.py', encoding='utf-8').read(), r'E:\Code\Minilite\tools\generate_mechanical.py', 'exec'), {'__file__': r'E:\Code\Minilite\tools\generate_mechanical.py', '__name__': '__main__'})"
```

Firmware source:

```powershell
python tools/generate_firmware.py
```

Release validation:

```powershell
python tools/validate_release.py
```

## 10. Manufacturing and release checklist

- Confirm two-copper-layer, 1.6 mm FR4 for both PCBs.
- Confirm all seven Gerber layers exist: F/B copper, F/B mask, F/B silkscreen,
  and Edge.Cuts.
- Include both PTH and NPTH drill files.
- Confirm main PCB DRC and carrier DRC each show zero violations and zero
  unconnected items.
- Confirm the plate vendor receives the fixed DXF and 1.5 mm thickness.
- Verify the exact purchased ZIF footprint against the board before ordering a
  production batch; generic 20P 1.0 mm connectors are not mechanically
  interchangeable.
- Buy a 21 mm-wide, 100 mm Type-A/same-side 20P 1.0 mm FFC.  Keep the installed
  service scroll at R3 or larger and never twist the cable around its long axis.
- Confirm M2 heat-set inserts are 3.2 mm nominal OD and 3 mm long before
  heating them into the 2.8 mm case pilots; tune the pilot on a test coupon if
  the actual insert knurl differs.
- For the A1 one-piece case, use the stored standing orientation and an
  8-10 mm brim; review supports before slicing.
- Print one plate half and a service-cover/carrier test before the full case.
- Test all 64 switch positions, USB enumeration, Vial unlock, and the boot key.
- Only after the prototype passes should the case tolerances be tuned for the
  chosen printer, filament, heat-set inserts, and screw supplier.

## 11. General lessons for the next project

- Use one coordinate-system conversion function and test it with asymmetric
  mounting features before placing hardware.
- Model screw heads, insert bosses, connector latch access, cable bends, and
  soldering access—not only nominal PCB outlines.
- Keep generated seeds and routed production boards in different paths.
- Make the release validator assert expected manufacturing layers; a board can
  pass copper DRC while still lacking declared mask layers.
- Stop and review from the assembler's point of view after every major layout
  change: what is installed first, what tool reaches the latch, what must be
  removed for service, and where slack cable goes.
- Preserve the original customer geometry, but publish a clearly named fixed
  derivative when a source drawing contains a known collision.

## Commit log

2026-07-22 Initial Minilite64 hardware, enclosure, firmware, and CI
    [BOM.csv, FFC_pinout.csv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]
2026-07-22 Clarify PCB copper layers and fix FreeCAD CI runner
2026-07-22 Rebuild enclosure with GH60 wedge geometry
    [Minilite64_assembly_review.FCStd, Minilite64_assembly_review.step, Minilite64_assembly_review.stl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]
2026-07-22 Add balanced bottom-row mounts and Case.step enclosure
    [BOM.csv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]
2026-07-22 Close RP2040 service cover button opening
    [Minilite64_assembly_review.FCStd, Minilite64_assembly_review.step, Minilite64_assembly_review.stl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]
2026-07-22 Remove obsolete split-print mechanical artifacts
    [Minilite64_case_A1_left.FCStd, Minilite64_case_A1_left.step, Minilite64_case_A1_left.stl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]
2026-07-22 Add printable anti-slip foot recesses
    [Minilite64_assembly_review.FCStd, Minilite64_assembly_review.step, Minilite64_assembly_review.stl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]
2026-07-22 Lower case to 20 mm spacebar edge
    [Minilite64_assembly_review.FCStd, Minilite64_assembly_review.step, Minilite64_assembly_review.stl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]
2026-07-22 Add A1 plate fit-check and PCB verification silk
    [Minilite64.kicad_pcb, Minilite64_plate_A1_fitcheck.stl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]
2026-07-22 Make A1 plate generation FreeCAD-compatible
    [Minilite64_plate_A1_fitcheck.stl]
2026-07-22 Finalize FFC routing and assembly-safe hardware
    [BOM.csv, FFC_pinout.csv, Minilite64.kicad_pcb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]
